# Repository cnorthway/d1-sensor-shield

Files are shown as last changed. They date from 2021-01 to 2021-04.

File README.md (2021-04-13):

# Wemos D1 Mini Sensor Shield

```
Note: This design was built using KiCad Nightly, and will only open in KiCad Nightly
```

To be used for a series of workshops given by the
Northeastern University Wireless Club.

Intended to be stacked on top of a Wemos D1 Mini. Contains temperature sensor,
photocell, SPI flash, and status LEDs.

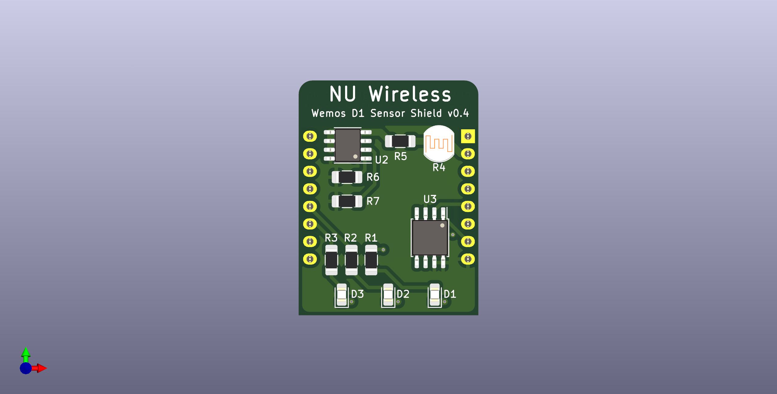
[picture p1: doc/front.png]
View of front side of PCB


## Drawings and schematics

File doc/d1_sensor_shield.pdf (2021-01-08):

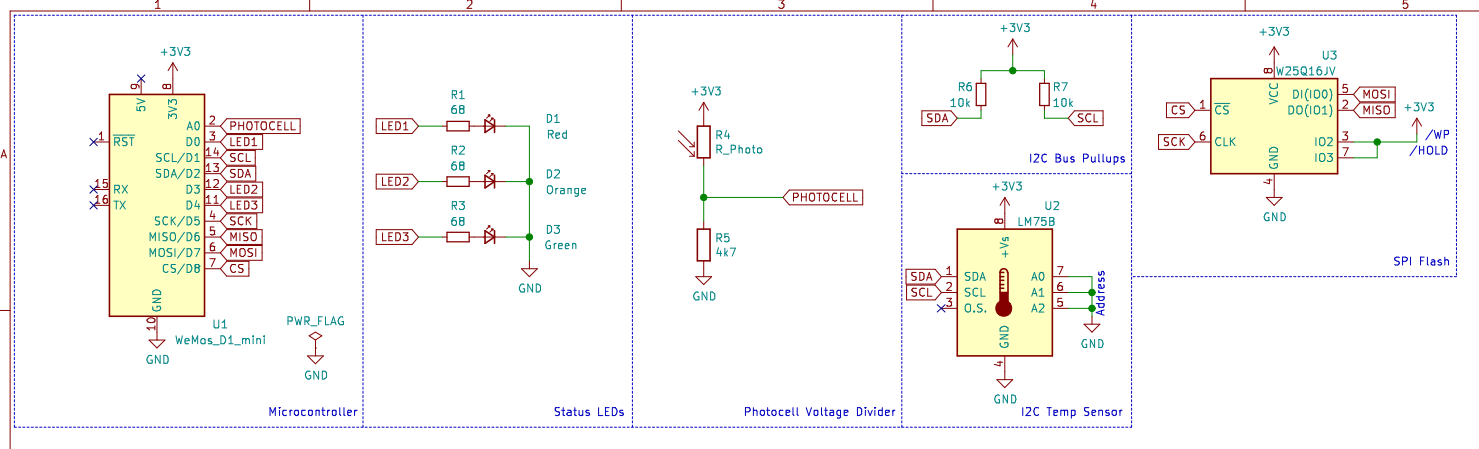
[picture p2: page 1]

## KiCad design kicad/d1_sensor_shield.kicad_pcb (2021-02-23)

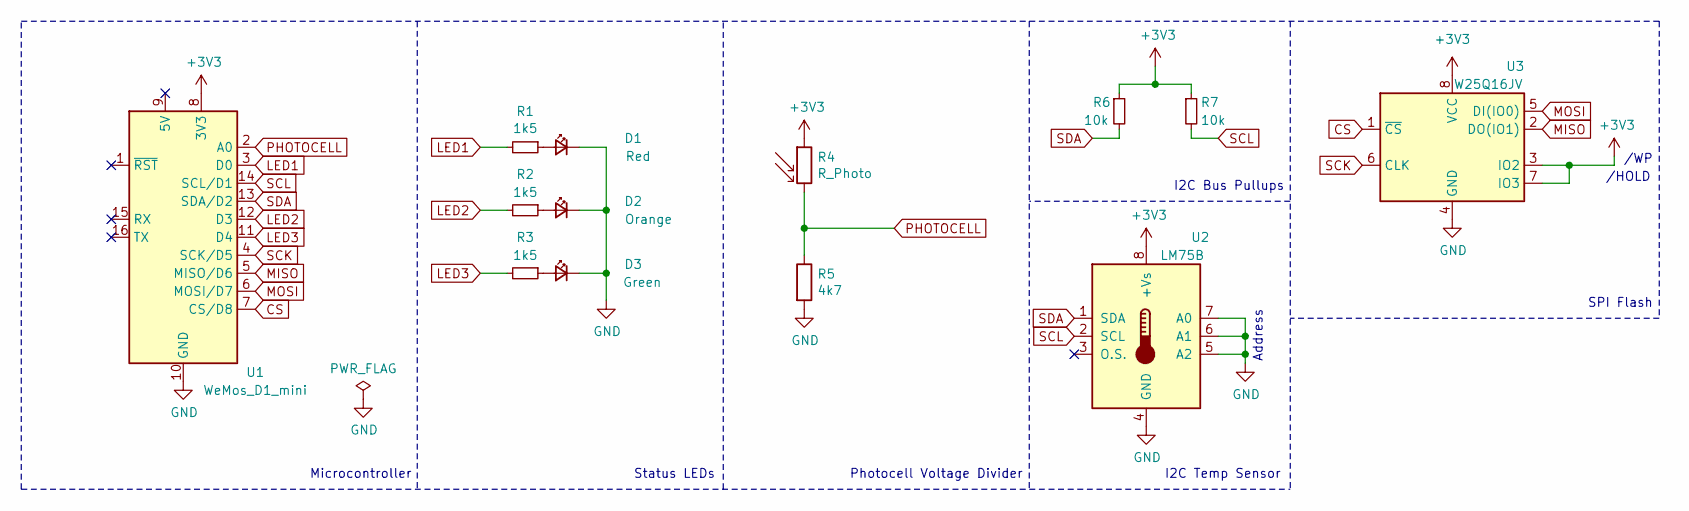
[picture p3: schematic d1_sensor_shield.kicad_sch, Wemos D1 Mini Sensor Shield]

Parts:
D1: Red; LED_0805_2012Metric_Pad1.15x1.40mm_HandSolder
D2: Orange; LED_0805_2012Metric_Pad1.15x1.40mm_HandSolder
D3: Green; LED_0805_2012Metric_Pad1.15x1.40mm_HandSolder
R1, R2, R3: 1k5; R_1206_3216Metric_Pad1.30x1.75mm_HandSolder
R4: R_Photo; R_LDR_5.1x4.3mm_P3.4mm_Vertical
R5: 4k7; R_1206_3216Metric_Pad1.30x1.75mm_HandSolder
R6, R7: 10k; R_1206_3216Metric_Pad1.30x1.75mm_HandSolder
U1: WeMos_D1_mini; WEMOS_D1_mini_light
U2: LM75B; SOIC-8_3.9x4.9mm_P1.27mm
U3: W25Q16JV; SOIC-8_5.23x5.23mm_P1.27mm

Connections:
+3V3: R4.1, R6.1, R7.1, U1.8 (3V3), U2.8 (+Vs), U3.3 (IO2), U3.7 (IO3), U3.8 (VCC)
CS: U1.7 (CS/D8), U3.1 (~CS)
GND: D1.1 (K), D2.1 (K), D3.1 (K), R5.2, U1.10 (GND), U2.4 (GND), U2.5 (A2), U2.6 (A1), U2.7 (A0), U3.4 (GND)
LED1: R1.2, U1.3 (D0)
LED2: R2.2, U1.12 (D3)
LED3: R3.2, U1.11 (D4)
MISO: U1.5 (MISO/D6), U3.2 (DO(IO1))
MOSI: U1.6 (MOSI/D7), U3.5 (DI(IO0))
unnamed: D1.2 (A), R1.1
unnamed: D2.2 (A), R2.1
unnamed: D3.2 (A), R3.1
PHOTOCELL: R4.2, R5.1, U1.2 (A0)
SCK: U1.4 (SCK/D5), U3.6 (CLK)
SCL: R7.2, U1.14 (SCL/D1), U2.2 (SCL)
SDA: R6.2, U1.13 (SDA/D2), U2.1 (SDA)

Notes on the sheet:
Microcontroller
Status LEDs
Photocell Voltage Divider
I2C Temp Sensor
I2C Bus Pullups
Address
SPI Flash
/HOLD
/WP

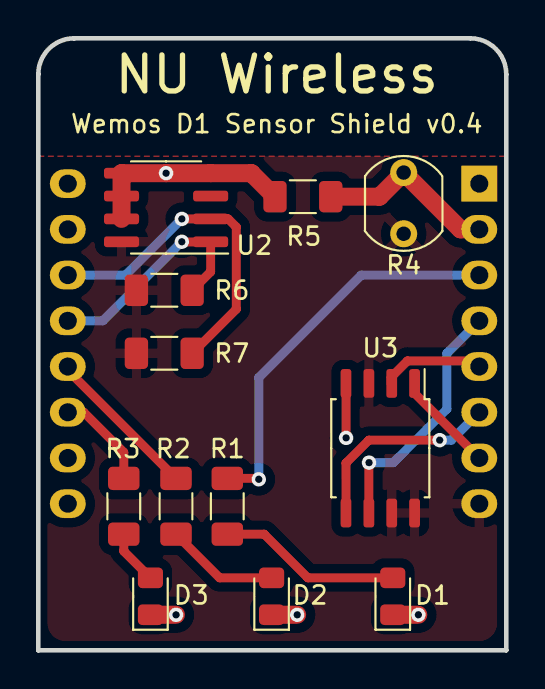
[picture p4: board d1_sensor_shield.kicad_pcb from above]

Board: 2 copper layers, 26.0 x 34.0 mm, 13 parts (1 on the bottom side), 15 nets.

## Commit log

2021-01-09 remove layer alignment target
    [d1_sensor_shield.kicad_pcb]
2021-01-09 Flip D1 to other side of board
    Wemos D1 footprint was incorrectly placed
    [d1_sensor_shield.kicad_pcb]
2021-01-12 Redo edge cuts in 10mil thickness, move silkscreen
    also shift oshw logo
    [d1_sensor_shield.kicad_pcb]
2021-02-14 Update SPI flash footprint, silkscreen
    [d1_sensor_shield.kicad_pcb, d1_sensor_shield.kicad_sch]
2021-02-23 widen photocell footprint
    [d1_sensor_shield.kicad_pcb, d1_sensor_shield.kicad_sch]
2021-02-23 v0.4, change size slightly
    [d1_sensor_shield.kicad_pcb]
2021-03-04 add interactive BOM file
2021-04-13 Add note about KiCad Nightly
